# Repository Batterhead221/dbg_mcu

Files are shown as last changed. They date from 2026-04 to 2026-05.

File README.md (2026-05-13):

# dbg_mcu (STM32_MICROCONTROLLER)

# V1.1

-USB-C (USB 2.0) STM32F072CBT6-based programmer/debug adapter board.

- USB-C powered + USB 2.0 device interface
- Target programming/debug via **SWD**
- Dedicated reset control and debug access points
- On-board power section (labeled **POWER**) with switching and protection components

## Hardware overview
- MCU: **STM32F072CBT6**
- USB: **USB-C 2.0** (device/UFP configuration)
- Debug: **SWDIO / SWCLK / NRST / GND**
- Board: **DEBUGGER_V1.0**

## Connectors & headers
- **USB-C**: primary power + USB data connection
- **J2 (DEBUG header)**: main target interface header (SWD + reset + power reference)
- **J1 / J3 / S1 / S2**: board configuration/jumper/select features (see silkscreen)

## Test points (silkscreen labels)
- **TP2_3V3**: 3.3V rail test point
- **TP3_GND**: ground reference test point
- **TP4_NRST**: target reset test point
- **TP5_SWDIO**: SWD data test point
- **TP6_SWCLK**: SWD clock test point

## On-board power (POWER block)
Located on the left side of the board (near **SW1** and components marked U3/U4).
- Input comes from USB-C 5V
- Generates and distributes rails used by the MCU/debug interface
- Protection/fusing present (F1)

## Buttons / switches
- **RESET area (SW2)**: reset functionality (see silkscreen)
- **SW1 (POWER area)**: power-related switching (see silkscreen)

## PROGRAM/DEBUG HEADER
J2 pinout reference:
- Pin 1: +3V3
- Pin 2: SWDIO
- Pin 3: GND
- Pin 4: SWCLK
- Pin 5: GND
- Pin 10: NRST

DESIGNED & ENGINEERED BY BRANDON SHELLY

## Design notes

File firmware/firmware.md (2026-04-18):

#NO FIRMWARE

BOARDHOUSE POPULATED WITH WRONG STM32 CHIP

POWERED UP - BUT NO FURTHER BRING-UP IS POSSIBLE AT THE MOMENT

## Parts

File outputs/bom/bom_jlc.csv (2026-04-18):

COMMENT | DESIGNATOR | FOOTPRINT | JLCPCB PART#
1UF | C1 | GRM155R71C104KA88D:CAPC1005X55N | GRT155R61A105KE01D
1UF | C5 | GRM155R71C104KA88D:CAPC1005X55N | GRT155R61A105KE01D
1UF | C6 | GRM155R71C104KA88D:CAPC1005X55N | GRT155R61A105KE01D
100NF | C2 | GRM155R71C104KA88D:CAPC1005X55N | GRM155R71H104KE14D
100NF | C4 | GRM155R71C104KA88D:CAPC1005X55N | GRM155R71H104KE14D
100NF | C8 | GRM155R71C104KA88D:CAPC1005X55N | GRM155R71H104KE14D
LED | D1 | SparkFun-LED:LED_0603_1608Metric | LTST-C190KGKT
POLYFUSE | F1 | SparkFun-PowerIC:PTC-1206 | MF-NSMF050-2
DF13A-4P-1.25H_21_ | J3 | DF13A-4P-1:HRS_DF13A-4P-1.25H_21_ | DF13A-4P-1.25H(21)
P-MOSFET transistor, drain/gate/source | Q1 | SparkFun-Semiconductor-Standard:SOT23-3 | AO3407A
0.2A Ic, 40V Vce, Small Signal NPN Transistor, SOT-23 | Q2 | Package_TO_SOT_SMD:SOT-23 | AO3400A
10K | R1 | CRCW060310K0FKEA:RESC1508X50N | RC0603FR-0710KL
10K | R4 | CRCW060310K0FKEA:RESC1508X50N | RC0603FR-0710KL
5.1K | R2 | CRCW060310K0FKEA:RESC1508X50N | RC0603FR-075K1L
5.1K | R3 | CRCW060310K0FKEA:RESC1508X50N | RC0603FR-075K1L
330 | R5 | CRCW060310K0FKEA:RESC1508X50N | RC0603FR-07330RL
100K | R6 | CRCW060310K0FKEA:RESC1508X50N | RC0603FR-07100KL
100K | R7 | CRCW060310K0FKEA:RESC1508X50N | RC0603FR-07100KL
110 | R11 | CRCW060310K0FKEA:RESC1508X50N | RC0603FR-07110RL
STM32 | U1 | Package_QFP:LQFP-48_7x7mm_P0.5mm | STM32F072CBT6
USBLC6-2P6 | U3 | Package_TO_SOT_SMD:SOT-666 | USBLC6-2P6
600mA low dropout linear regulator, with enable pin, 3.8V-6V input voltage range, 3.3V fixed positive output, SOT-23-5 | U4 | SparkFun-Semiconductor-Standard:SOT23-5 | AP2112K-3.3TRG1
Hall effect switch, unipolar (south-polarity), Bop=70-350G, Brp=50-330G, 3.8-24V supply, SOT-23W | U5 | Package_TO_SOT_SMD:SOT-23W | AH1806-W-7

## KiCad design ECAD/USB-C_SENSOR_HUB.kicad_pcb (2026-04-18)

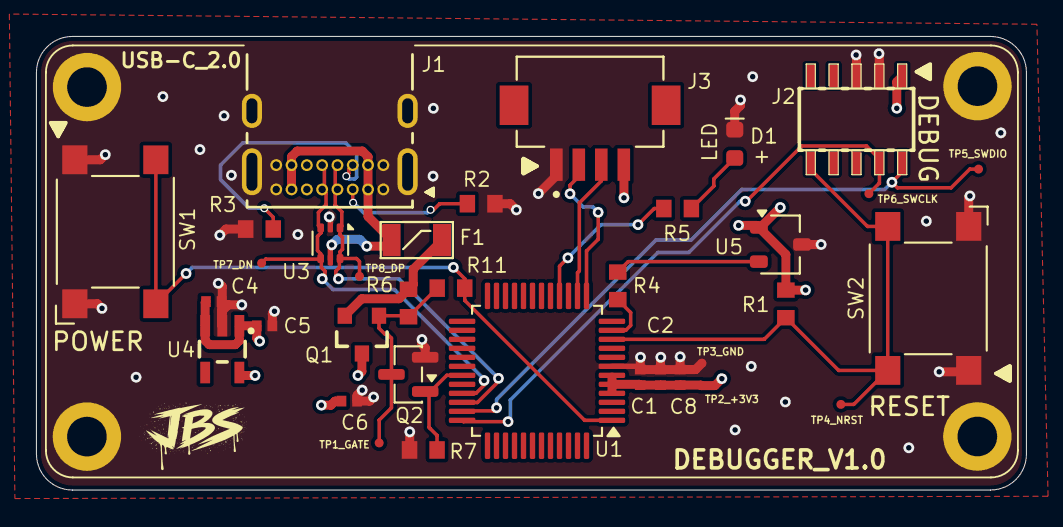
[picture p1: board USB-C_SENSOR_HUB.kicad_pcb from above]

Board: 4 copper layers, 55.0 x 25.2 mm, 38 parts (0 on the bottom side), 21 nets.

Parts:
C1, C5, C6: 1UF; CAPC1005X55N
C2, C8: 100NF; CAPC1005X55N
C4: 0.1UF; CAPC1005X55N
D1: LED; LED_0603_1608Metric
F1: POLYFUSE; PTC-1206
J1: USB_C_Receptacle; CONN16_USB4085-GF-A_GCT
J2: CORTEX_DEBUGSMD; SAMTECH_FTSH-105-01
J3: DF13A-4P-1.25H_21_; HRS_DF13A-4P-1.25H_21_
MH: (no value)
MH#2, MH#3: (no value)
Q1: P-MOS; SOT23-3
Q2: N-MOS; SOT-23
R1, R4: 10K^; RESC1508X50N
R2, R3: 5.1K; RESC1508X50N
R5: 330; RESC1508X50N
R6, R7: 100K; RESC1508X50N
R11: 110; RESC1508X50N
SW1, SW2: SW_Push; SW_SPST_Omron_B3FS-101xP
TP1_GATE, TP2_+3V3, TP3_GND, TP4_NRST, TP5_SWDIO, TP6_SWCLK, TP7_DN, TP8_DP: 0.5mm; TestPoint-0.5mm
U1: STM32; LQFP-48_7x7mm_P0.5mm
U3: USBLC6-2P6; SOT-666
U4: V-REG; SOT23-5
U5: HALL_FX; SOT-23W

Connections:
/+3V3: C1.1, C2.1, C6.1, C8.1, J2.1 (VCC), J3.4, R1.1, TP2_+3V3.1, U1.4 (VBAT), U1.5 (VREF+), U1.6 (VDD), U4.5 (VOUT), U5.1 (V_{CC})
/CC1: J1.A5 (3), R2.2
/CC2: J1.B5 (14), R3.2
/HALL_OUT: R4.2, U1.11 (PA0)
/LED_STATUS: R5.2, U1.16 (PA5)
/NRST: J2.10 (NRESET), R1.2, SW2.2, TP4_NRST.1, U1.10 (PF2)
/PWR_BTN: R11.1, SW1.2, U1.1 (PC13)
/PWR_GATE: Q1.1 (G), Q2.3 (C), R6.1, R11.2, TP1_GATE.1
/PWR_HOLD: Q2.1 (B), R7.1, U1.31 (PC7)
/RAW_IN: F1.2, Q1.2 (S), R6.2
/SWCLK: J2.4 (SWDCLK/TCK), TP6_SWCLK.1, U1.36 (PA14)
/SWDIO: J2.2 (SWDIO/TMS), TP5_SWDIO.1, U1.35 (PA13)
/UART_RX: J3.3, U1.14 (PA3)
/UART_TX: J3.2, U1.13 (PA2)
/USB_N: J1.A7 (5), J1.B7 (12), TP7_DN.1, U1.33 (PA9/PA11), U3.3 (I/O2), U3.4 (I/O2)
/USB_P: J1.A6 (4), J1.B6 (13), TP8_DP.1, U1.34 (PA10/PA12), U3.1 (I/O1), U3.6 (I/O1)
/VBUS: F1.1, J1.A4 (2), J1.A9 (7), J1.B4 (15), J1.B9 (10), U3.5 (VBUS)
/VIN_SYS: C4.1, C5.1, Q1.3 (D), U4.1 (VIN), U4.3 (EN)
GND: C1.2, C2.2, C4.2, C5.2, C6.2, C8.2, D1.1 (K), J1.A1 (1), J1.A12 (8), J1.B1 (16), J1.B12 (9), J1.S1 (SHIELD), J2.3 (GND), J2.5 (GND), J3.1, MH.1, MH#2.1, MH#3.1, Q2.2 (E), R2.1, R3.1, R7.2, SW1.1, SW2.1, TP3_GND.1, U1.7 (VSS), U3.2 (GND), U4.2 (GND), U5.3 (GND)
unnamed: D1.2 (A), R5.1
unnamed: R4.1, U5.2 (V_{OUT})

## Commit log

2026-04-18 file path restructure
    [USB-C_SENSOR_HUB.kicad_pcb, USB-C_SENSOR_HUB.kicad_sch, bom_jlc.csv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]
2026-05-03 folder restructure
    [USB-C_SENSOR_HUB.kicad_pcb, USB-C_SENSOR_HUB.kicad_sch, bom_jlc.csv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]
2026-05-13 Revised repo
    [USB-C_SENSOR_HUB.kicad_pcb, USB-C_SENSOR_HUB.kicad_sch]
